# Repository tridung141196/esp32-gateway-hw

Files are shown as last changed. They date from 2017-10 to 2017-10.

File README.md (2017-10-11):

# esp32-gateway-hw

## Features

esp32-gateway-hw có thể:
- Điện áp ngõ vào 4 đến 40VDC.

- Sử dụng được nguồn DC, USB, Pin ( có chức năng tự sạc).

- Theo dõi vị trí và trả về thông tin cho người dùng thông qua module GPS Neo6m và module GSM Sim800c.

- Hệ thống đèn báo nguồn , GPS , GSM.

# Nguyên lý hoạt động

- SHield sử dụng module GPS neo6m để định vị tọa độ của thiết bị thông qua hệ thống định vị toàn cầu (GPS) sau đó gửi thông tin toạ độ thiết bị đến người dùng thông qua module sim800c

## Hardware

### Các module đi kèm

ESP32-WROVER-V3

GSM SIM800C

GPS NEO6M

### Schematics

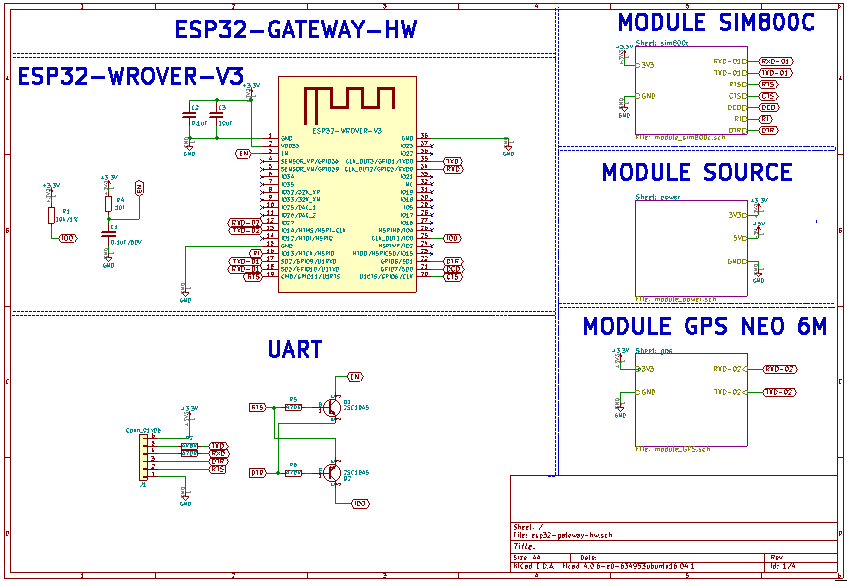
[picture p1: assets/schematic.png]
Schematic


### PCB Layout

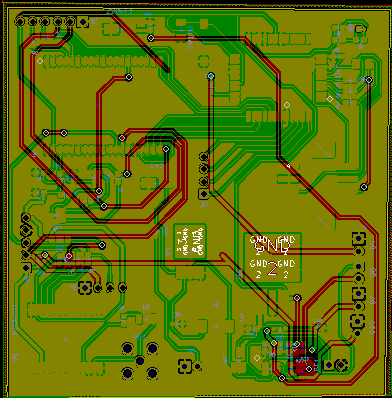
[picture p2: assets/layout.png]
PCB


### 3D

### Gerber

//[Download](./assets/esp32-cam-shield.zip)

### BOM 

| Designator | Package | Quantity | Designation  |
|---|---|---|---|
|		 |		 |	  |	 |
### Remark

This project was in development phase - we will remove this remark after release

# License

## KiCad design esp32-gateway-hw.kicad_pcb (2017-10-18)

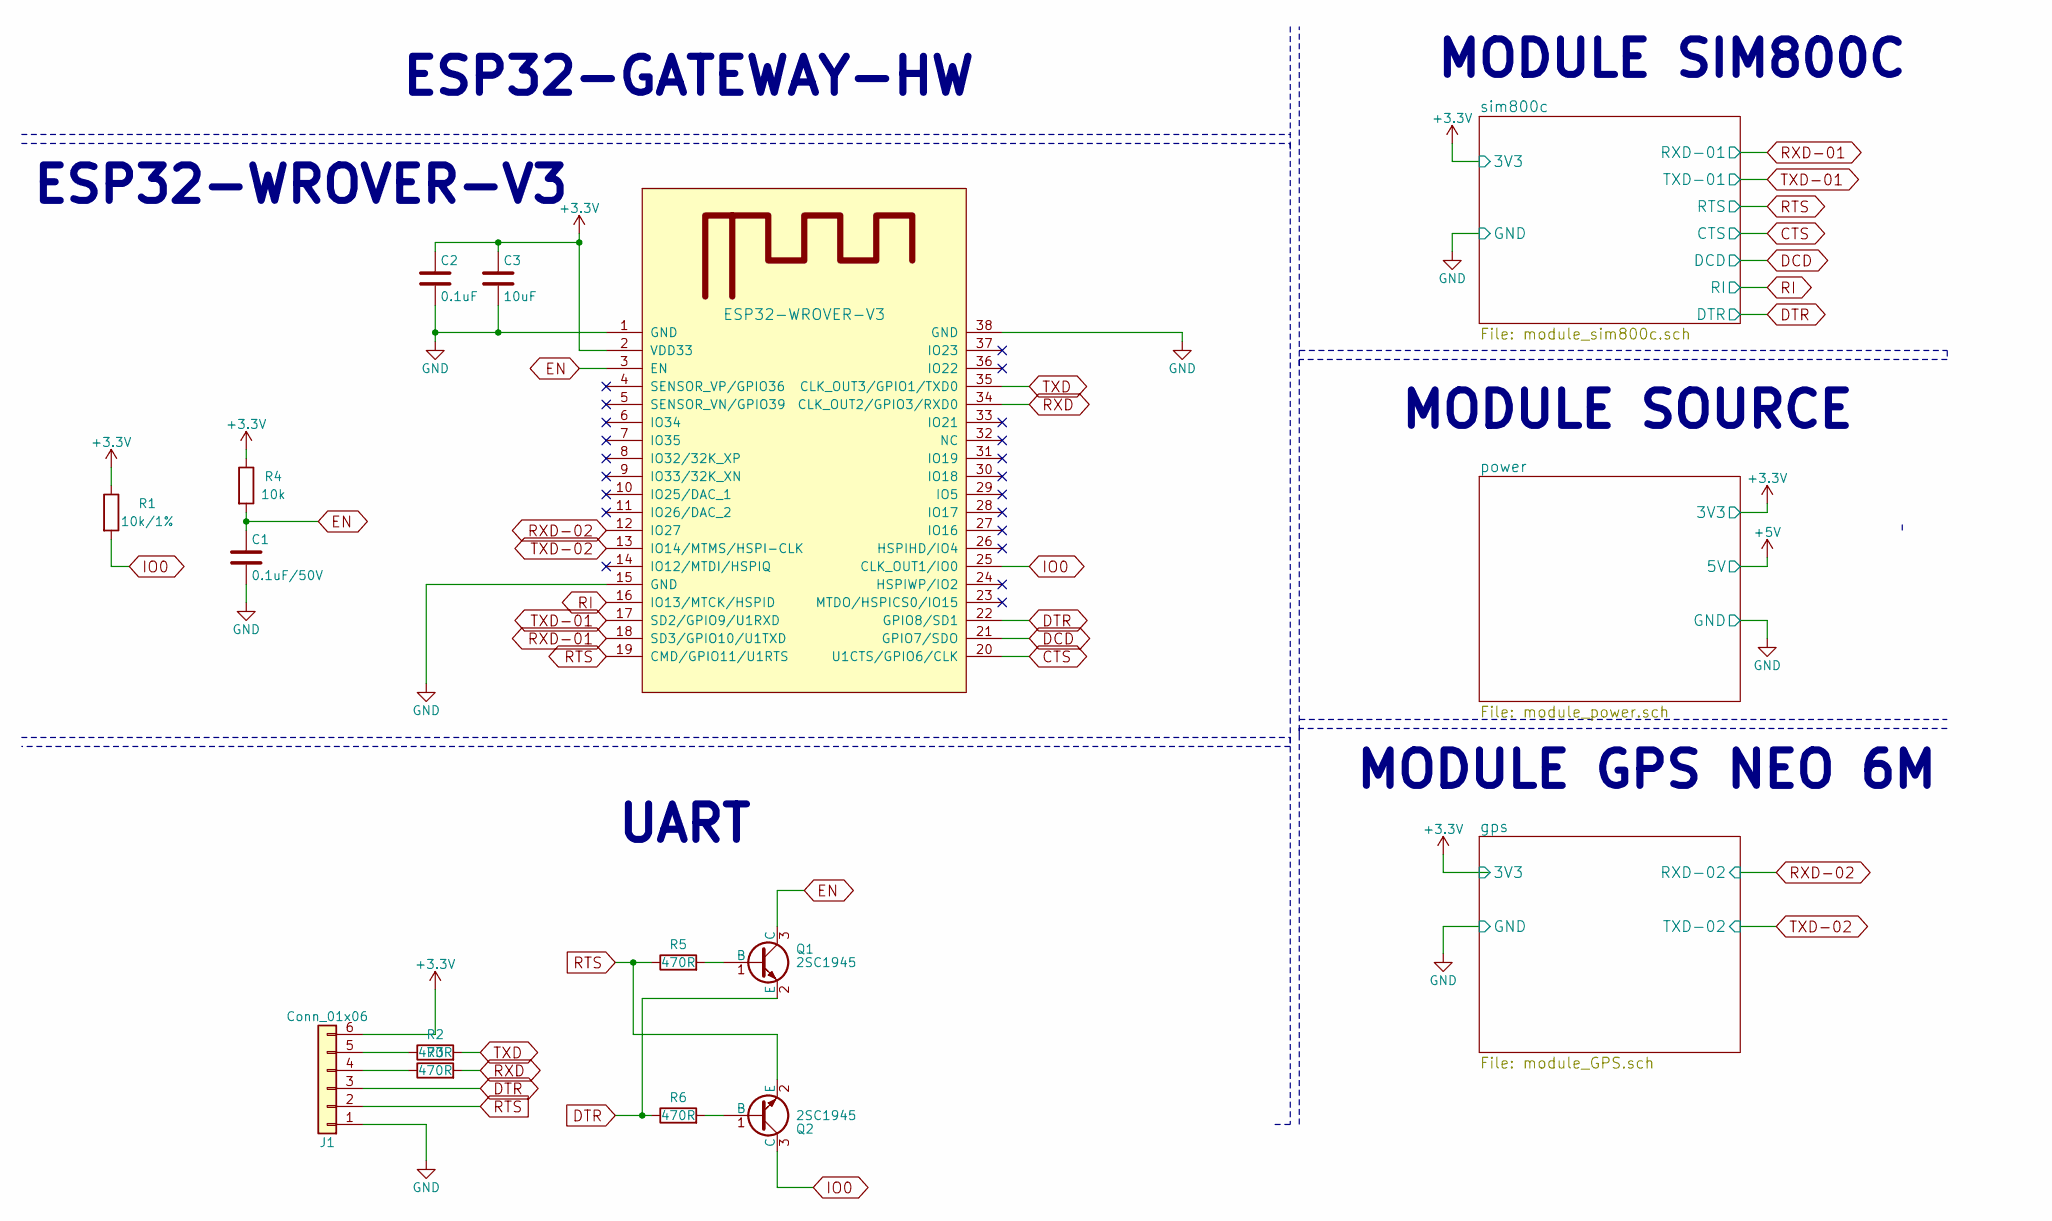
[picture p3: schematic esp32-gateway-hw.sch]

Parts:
C1: 0.1uF/50V; C_0603
C2: 0.1uF; C_0603
C3: 10uF; C_0603
J1: Conn_01x06; Pin_Header_Straight_1x06_Pitch2.54mm
Q1, Q2: 2SC1945; SOT-23
R1: 10k/1%; R_0603
R2, R3, R5, R6: 470R; R_0603
R4: 10k; R_0603
U1: ESP32-WROVER-V3; esp32-wrover-32S

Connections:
+3V3: C2.1, C3.1, J1.6, R1.1, R4.1, U1.2 (VDD33); also elsewhere on the board
CTS: U1.20 (U1CTS/GPIO6/CLK); also elsewhere on the board
DCD: U1.21 (GPIO7/SDO); also elsewhere on the board
DTR: J1.3, Q1.2 (E), R6.1, U1.22 (GPIO8/SD1); also elsewhere on the board
EN: C1.1, Q1.3 (C), R4.2, U1.3 (EN)
GND: C1.2, C2.2, C3.2, J1.1, U1.1 (GND), U1.15 (GND), U1.38 (GND); also elsewhere on the board
IO0: Q2.3 (C), R1.2, U1.25 (CLK_OUT1/IO0)
unnamed: J1.4, R3.1
unnamed: J1.5, R2.1
unnamed: Q1.1 (B), R5.2
unnamed: Q2.1 (B), R6.2
RI: U1.16 (IO13/MTCK/HSPID); also elsewhere on the board
RTS: J1.2, Q2.2 (E), R5.1, U1.19 (CMD/GPIO11/U1RTS); also elsewhere on the board
RXD: R3.2, U1.34 (CLK_OUT2/GPIO3/RXD0)
RXD-01: U1.18 (SD3/GPIO10/U1TXD); also elsewhere on the board
RXD-02: U1.12 (IO27); also elsewhere on the board
TXD: R2.2, U1.35 (CLK_OUT3/GPIO1/TXD0)
TXD-01: U1.17 (SD2/GPIO9/U1RXD); also elsewhere on the board
TXD-02: U1.13 (IO14/MTMS/HSPI-CLK); also elsewhere on the board

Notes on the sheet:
ESP32-GATEWAY-HW
MODULE GPS NEO 6M
MODULE SOURCE
MODULE SIM800C
ESP32-WROVER-V3
UART

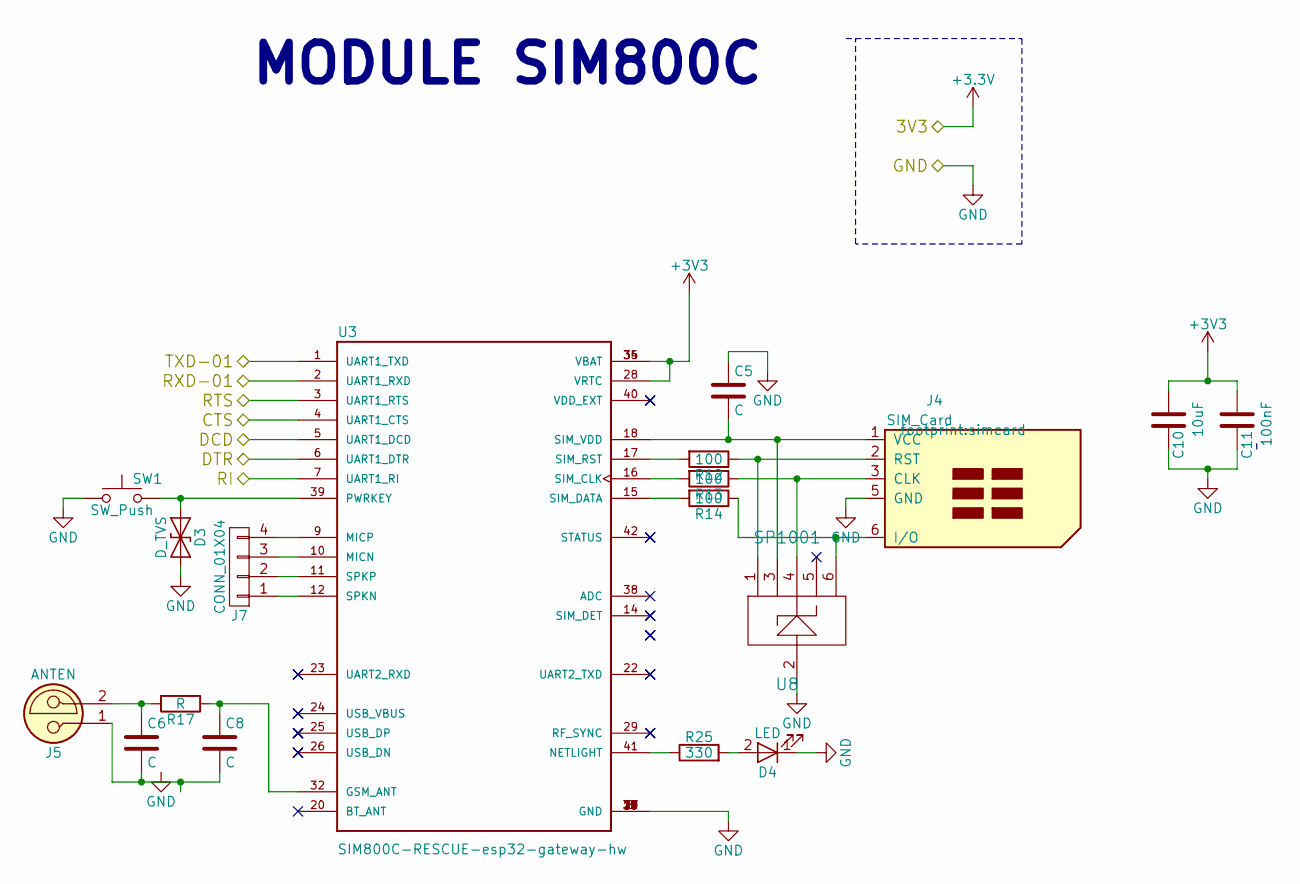
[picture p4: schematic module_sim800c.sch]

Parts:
C5, C6, C8: C; C_0603
C10: 10uF; C_0603
C11: 100nF; C_0603
D3: D_TVS; D_1206
D4: LED; LED_D3.0mm
J4: SIM_Card; simcard
J5: ANTEN; SMA_Straight
J7: CONN_01X04; Pin_Header_Straight_1x04_Pitch2.54mm
R12, R13, R14: 100; R_0603
R17: R; R_0603
R25: 330; R_0603
SW1: SW_Push; Tact_Switch_TS6X3.6
U3: SIM800C-RESCUE-esp32-gateway-hw; sim800c
U8: SP1001

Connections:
+3V3: C10.2, C11.2, U3.28 (VRTC), U3.34 (VBAT), U3.35 (VBAT); also elsewhere on the board
CTS: U3.4 (UART1_CTS); also elsewhere on the board
DCD: U3.5 (UART1_DCD); also elsewhere on the board
DTR: U3.6 (UART1_DTR); also elsewhere on the board
GND: C5.1, C10.1, C11.1, D3.2 (A2), D4.1 (K), J4.5 (GND), SW1.1, U3.8 (GND), U3.13 (GND), U3.19 (GND), U3.21 (GND), U3.27 (GND), U3.30 (GND), U3.31 (GND), U3.33 (GND), U3.36 (GND), U3.37 (GND), U8.2; also elsewhere on the board
unnamed: C5.2, J4.1 (VCC), U3.18 (SIM_VDD), U8.3
unnamed: C6.1, J5.2, R17.2
unnamed: C6.2, C8.2, J5.1
unnamed: C8.1, R17.1, U3.32 (GSM_ANT)
unnamed: D3.1 (A1), SW1.2, U3.39 (PWRKEY)
unnamed: D4.2 (A), R25.2
unnamed: J4.2 (RST), R12.1, U8.1
unnamed: J4.3 (CLK), R13.1, U8.4
unnamed: J4.6 (I/O), R14.1, U8.6
unnamed: J7.1, U3.12 (SPKN)
unnamed: J7.2, U3.11 (SPKP)
unnamed: J7.3, U3.10 (MICN)
unnamed: J7.4, U3.9 (MICP)
unnamed: R12.2, U3.17 (SIM_RST)
unnamed: R13.2, U3.16 (SIM_CLK)
unnamed: R14.2, U3.15 (SIM_DATA)
unnamed: R25.1, U3.41 (NETLIGHT)
RI: U3.7 (UART1_RI); also elsewhere on the board
RTS: U3.3 (UART1_RTS); also elsewhere on the board
RXD-01: U3.2 (UART1_RXD); also elsewhere on the board
TXD-01: U3.1 (UART1_TXD); also elsewhere on the board

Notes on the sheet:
MODULE SIM800C

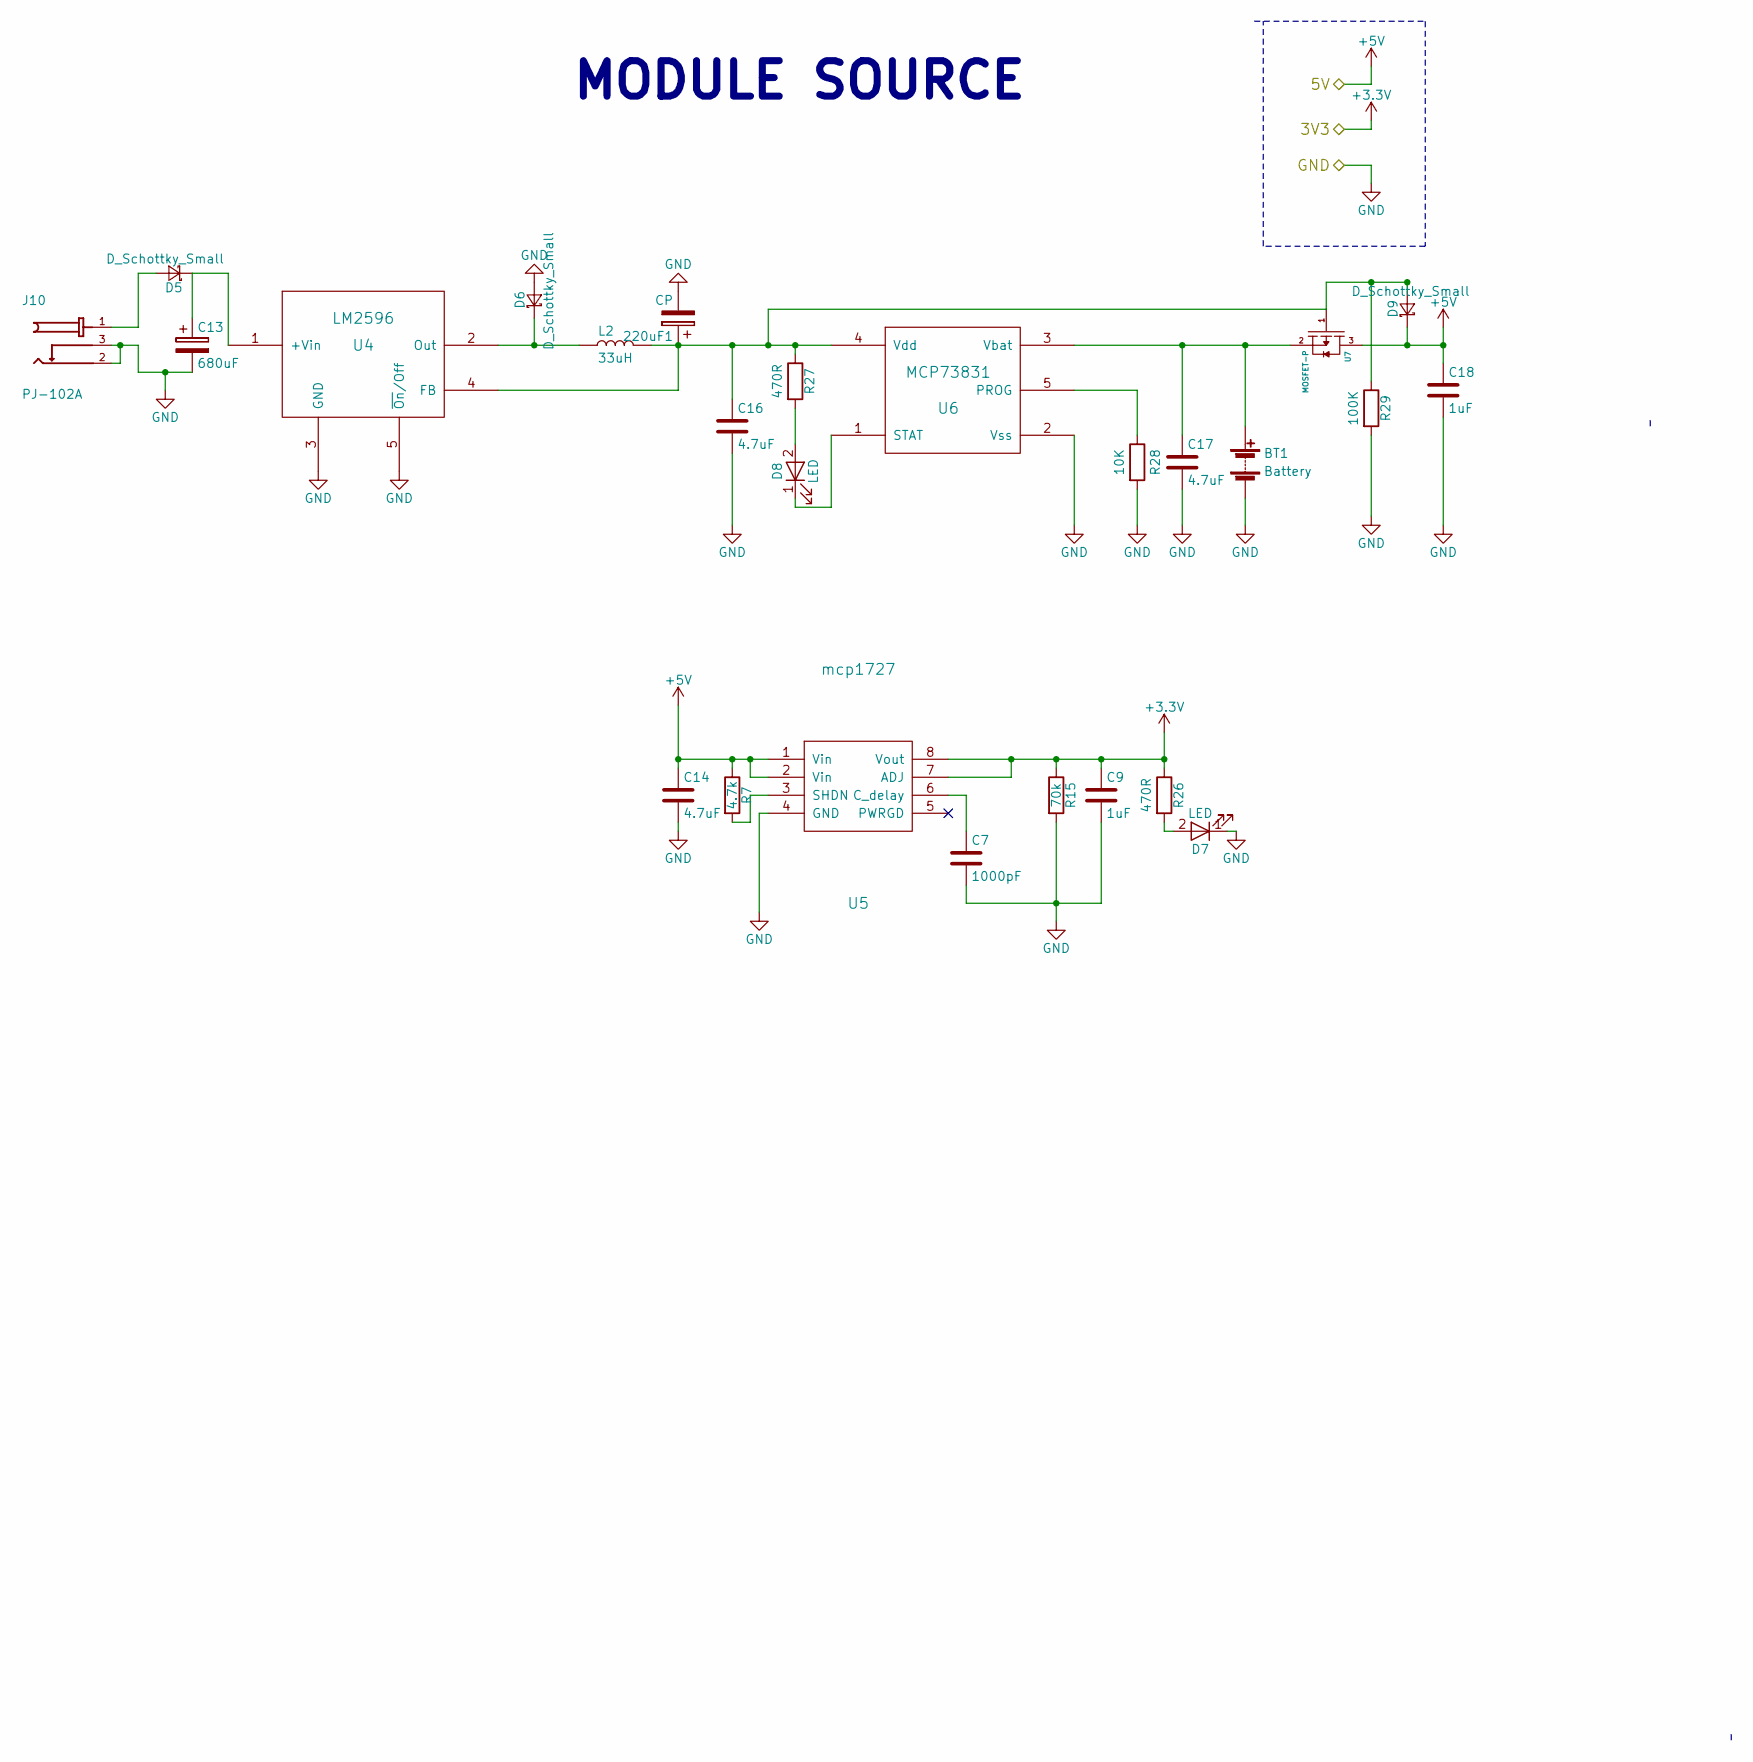
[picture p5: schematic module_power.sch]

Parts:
220uF1: CP; CP_Elec_4x4.5
BT1: Battery; Pin_Header_Straight_1x02_Pitch2.54mm
C7: 1000pF; C_0603
C9, C18: 1uF; C_0603
C13: 680uF; CP_Radial_D10.0mm_P5.00mm
C14, C16, C17: 4.7uF; C_0603
D5, D6, D9: D_Schottky_Small; D_SOD-323
D7, D8: LED; LED_D3.0mm
J10: PJ-102A; jackdc
L2: 33uH; L_6.3x6.3_H3
R7: 4.7k; R_0603
R15: 70k; R_0603
R26, R27: 470R; R_0603
R28: 10K; R_0603
R29: 100K; R_0603
U4: LM2596; TO-252-5_TabPin3
U5: mcp1727
U6: MCP73831; SOT-23-5
U7: MOSFET-P; SOT-23_Handsoldering

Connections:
+3V3: C9.1, R15.1, R26.1, U5.7 (ADJ), U5.8 (Vout); also elsewhere on the board
+5V: C14.1, C18.1, D9.1 (K), R7.1, U5.1 (Vin), U5.2 (Vin), U7.3
GND: 220uF1.2, BT1.2 (-), C7.2, C9.2, C13.2, C14.2, C16.2, C17.2, C18.2, D6.2 (A), D7.1 (K), J10.2, J10.3, R15.2, R28.2, R29.2, U4.3 (GND), U4.5 (~On~/Off), U5.4 (GND), U6.2 (Vss); also elsewhere on the board
unnamed: 220uF1.1, C16.1, D9.2 (A), L2.2, R27.1, R29.1, U4.4 (FB), U6.4 (Vdd), U7.1
unnamed: BT1.1 (+), C17.1, U6.3 (Vbat), U7.2
unnamed: C7.1, U5.6 (C_delay)
unnamed: C13.1, D5.1 (K), U4.1 (+Vin)
unnamed: D5.2 (A), J10.1
unnamed: D6.1 (K), L2.1, U4.2 (Out)
unnamed: D7.2 (A), R26.2
unnamed: D8.1 (K), U6.1 (STAT)
unnamed: D8.2 (A), R27.2
unnamed: R7.2, U5.3 (SHDN)
unnamed: R28.1, U6.5 (PROG)

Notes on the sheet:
MODULE SOURCE

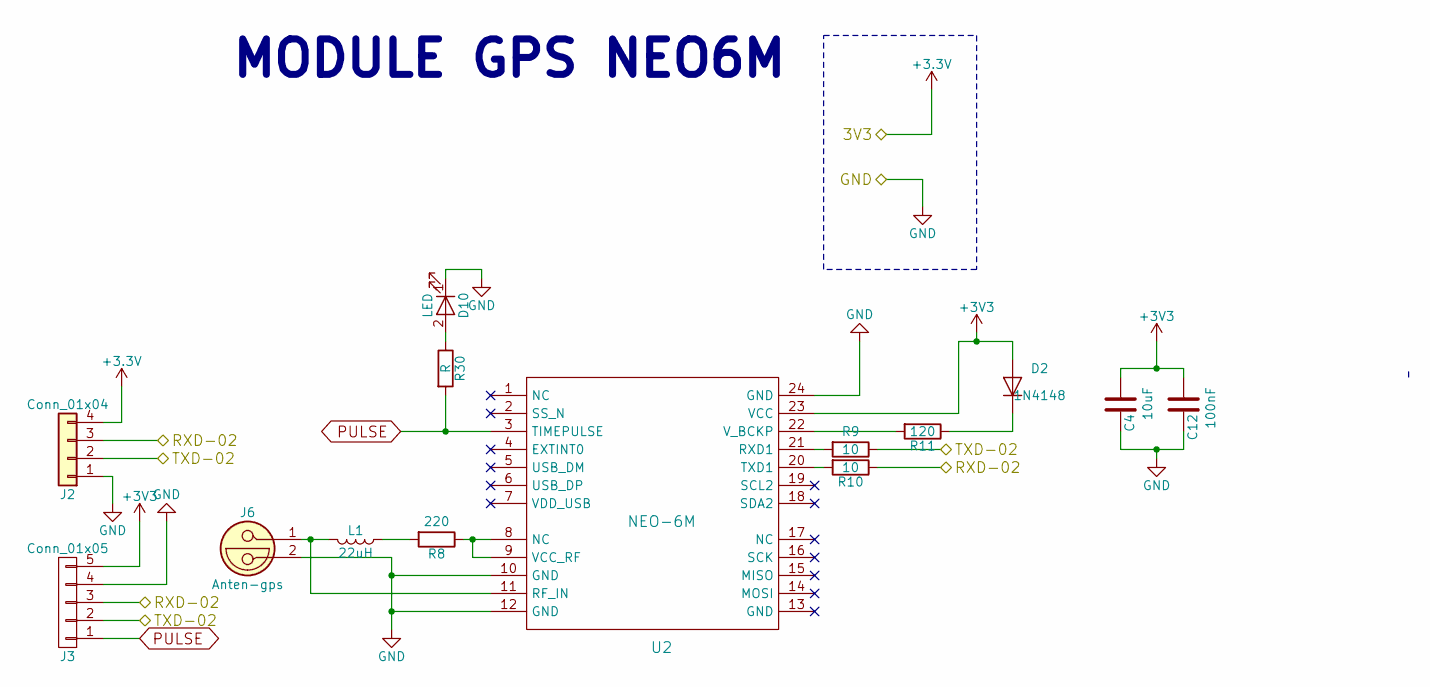
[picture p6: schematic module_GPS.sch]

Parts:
C4: 10uF; C_0603
C12: 100nF; C_0603
D2: 1N4148; D_SOD-123
D10: LED; LED_D3.0mm
J2: Conn_01x04; Pin_Header_Straight_1x04_Pitch2.54mm
J3: Conn_01x05; Pin_Header_Straight_1x05_Pitch2.54mm
J6: Anten-gps; SMA_Straight
L1: 22uH; L_1206
R8: 220; R_0603
R9, R10: 10; R_0603
R11: 120; R_0603
R30: R; R_0603
U2: NEO-6M; gps-neo6m

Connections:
+3V3: C4.2, C12.2, D2.2 (A), J2.4, J3.5, U2.23 (VCC); also elsewhere on the board
GND: C4.1, C12.1, D10.1 (K), J2.1, J3.4, J6.2, U2.10 (GND), U2.12 (GND), U2.24 (GND); also elsewhere on the board
unnamed: D2.1 (K), R11.1
unnamed: D10.2 (A), R30.1
unnamed: J6.1, L1.2, U2.11 (RF_IN)
unnamed: L1.1, R8.2
unnamed: R8.1, U2.8 (NC), U2.9 (VCC_RF)
unnamed: R9.2, U2.21 (RXD1)
unnamed: R10.2, U2.20 (TXD1)
unnamed: R11.2, U2.22 (V_BCKP)
PULSE: J3.1, R30.2, U2.3 (TIMEPULSE)
RXD-02: J2.3, J3.3, R10.1; also elsewhere on the board
TXD-02: J2.2, J3.2, R9.1; also elsewhere on the board

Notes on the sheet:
MODULE GPS NEO6M

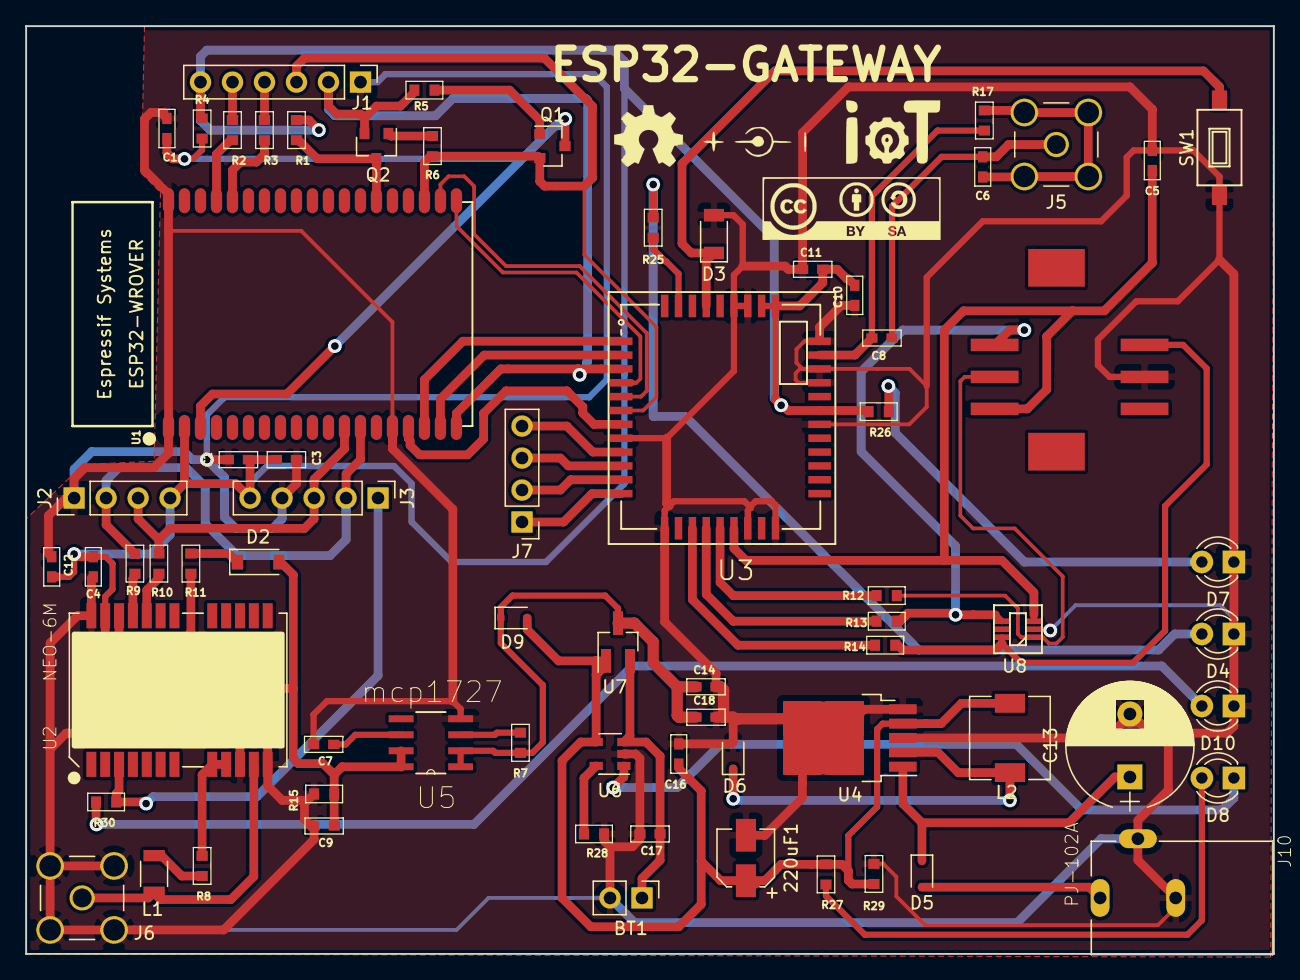
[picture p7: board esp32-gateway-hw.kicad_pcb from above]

Board: 2 copper layers, 99.1 x 73.7 mm, 71 parts (0 on the bottom side), 57 nets.

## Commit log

2017-10-10 new file module power
    [file59DC73D1.sch]
2017-10-10 tong hop module
    [esp32-gateway-hw.sch, module_GPS.sch, module_sim800c.sch]
2017-10-10 complete schematic
    [esp32-gateway-hw.sch, file59DC73D1.sch, module_GPS.sch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]
2017-10-10 fix usb uart
    [esp32-gateway-hw.sch, module_GPS.sch, module_power.sch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]
2017-10-10 add footprint neo-6m
2017-10-10 edit module sim800c
    [esp32-gateway-hw.sch, module_GPS.sch, module_power.sch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]
2017-10-11 add footprint sim 800
2017-10-11 fix mach nap
    [esp32-gateway-hw.sch, module_GPS.sch, module_power.sch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]
2017-10-11 update layout
    [esp32-gateway-hw.kicad_pcb, esp32-gateway-hw.sch, module_GPS.sch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]
2017-10-11 edit sheet module
    [esp32-gateway-hw.kicad_pcb, esp32-gateway-hw.sch, module_GPS.sch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]
2017-10-11 edit readme
    [esp32-gateway-hw.kicad_pcb]
2017-10-11 edit schematic
    [esp32-gateway-hw.sch, module_GPS.sch, module_power.sch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]
2017-10-17 add footprint mcp1727
    [esp32-gateway-hw.kicad_pcb, esp32-gateway-hw.sch, module_GPS.sch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]
2017-10-18 edit layout
    [esp32-gateway-hw.kicad_pcb, esp32-gateway-hw.sch, module_GPS.sch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]
2017-10-18 edit pcd
    [esp32-gateway-hw.kicad_pcb]
